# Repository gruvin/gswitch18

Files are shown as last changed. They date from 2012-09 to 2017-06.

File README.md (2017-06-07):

# 18 Switch USB HID class 'Game Controller'

This project implements a USB 'Game Controller' with 18 switch (or button) interface ports, intended 
for use with PC flight simulators, to give additional inputs for external control panels.

No drivers required. 

# About This Project

A friend and I wanted a compact USB game controller interface, to provide at
least 10 switch inputs -- primarily for use with MS Flight Sim X and later, Condor Sailplane simulator.

I had experience with Atmel AVR chips. But I had never worked with USB before. Some Googling quickly 
found Objective Development's [V-USB project](http://www.obdev.at/products/vusb/index.html).

So, I started with a [KiCAD](http://www.kicad-pcb.org) design ...

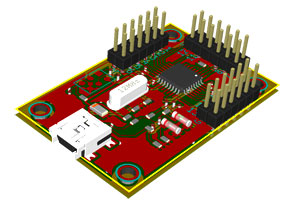
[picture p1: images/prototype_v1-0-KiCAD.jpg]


... and ended up with a working v1.0 prototype ...

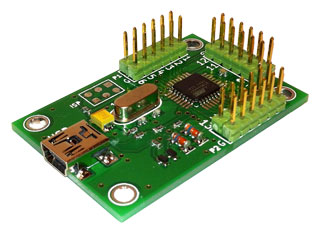
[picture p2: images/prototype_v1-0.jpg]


The image below shows Windows 7 Game Controller Settings / Properties ...

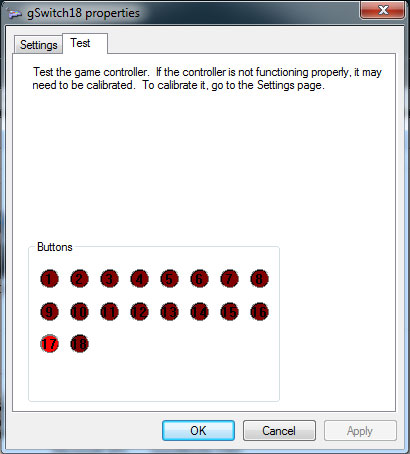
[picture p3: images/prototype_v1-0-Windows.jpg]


Of course, multipleor even all buttons can be used at once.

# Implementation Summary

This board uses an ATmega88p clocked at 12MHz, implementing a V-USB powered
(bit-bang) USB HID compliant game controller interface.

Since this is an HID compliant 'Game Controller' device, no drivers are
required for the host system, which is nice.

I use KiCAD as the PCB design (EDA) suite, only because it is completely free
(as in 'speech' _and_ 'beer') and I have used it very successfully before, for
another, [much larger project](https://github.com/gruvin/gruvin9x).

We get production quality, "prototype" PCB's made in China, using [ITead Studio](http://imall.iteadstudio.com/)'s 
[Open PCB prototyping service](http://imall.iteadstudio.com/open-pcb/pcb-prototyping.html).
These are high quality, fully clear routed, masked and silk-screened, all at a
fraction the price of bare copper, no mask, no silk-screen prototype boards
from, 'the West' and yet also just a fraction the price!

# Make Your Own
All the design files for the PCB (KiCAD) and the Atmel AVR source code is here in this Git repository. Go for it! :-)

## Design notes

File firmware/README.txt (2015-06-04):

This is the source code and hardware design package for the 
gswitch18 USB 18-switch HID 'Game Controller'.

https://github.com/gruvin/gswitch18

The PCB design (in ../hardware/) was created using KiCAD (Windows 7, under VMWare Fusion 5.)

The source code in this folder was developed using GNU avr-gcc, under Apple OS X.

SPECIAL THANKS to Objective Development for their excellent V-USB project 
(http://www.obdev.at/products/vusb/index.html) and to Joonas Pihlajamaa's 
AVR ATtiny USB HID Tutorial, published at his Code and Life blog, 
http://codeandlife.com.

Thanks also to my good friend Shamir, who gave me the idea to do this in 
the first placeand to my beloved wife Berlinda, for putting up with the late 
nights of coding for this and other projects. You're the best!

-- 
Gruvin

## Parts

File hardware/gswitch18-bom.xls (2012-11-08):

nz.element14.com 'next day delivery' cheapest pricing BOM
gswitch18 |  |  |  | as at 2012-11-08
 |  | Farnell UK |  |  |  |  |  |  |  | Per Build | MOQ Qty
Part Ref(s). | Farnell Part No. | Manufacturer | Mfr Part No. | Description | Value | Package | Qty | MOQ | Price Ea. | Amount | Amount
C3, C4 | 721992 (http://nz.element14.com/yageo-phycomp/cc0603jrnpo9bn180/capacitor-0603-18pf-50v/dp/721992) | Yageo | CC0603JRNPO9BN180 | Capacitor (ceramic) | 18p | SM0603 | 2 | 10 | 0.064 | 0.13 | 0.64
C1 | 1362556 (http://nz.element14.com/yageo-phycomp/cc0603krx7r9bb104/capacitor-0603-100nf-50v-x7r/dp/1362556) | Yageo | CC0603KRX7R9BB104 | Capacitor (ceramic) | 0u1 | SM0603 | 2 | 10 | 0.078 | 0.16 | 0.78
C2 | 1862119 (http://nz.element14.com/avx/tajb226k016rnj/capacitor-tant-22uf-16v-2-3ohm/dp/1862119) | AVX | TAJB226K016RNJ | Capacitor (tantalum) | 22u | SM1210 | 1 | 1 | 1.600 | 1.60 | 1.60
R1, R2 | 9330950 (http://nz.element14.com/multicomp/mc-0-063w-0603-1-27r/resistor-0603-27r/dp/9330950) | Multicomp | MC 0.063W 0603 1% 27R | Resistor (thick-film) | 27R | SM0603 | 2 | 50 | 0.010 | 0.02 | 0.50
R5, R6 | 9332138 (http://nz.element14.com/multicomp/mc-0-063w-0603-5-47r/resistor-0603-47r/dp/9332138) | Multicomp | MC 0.063W 0603 5% 47R | Resistor (thick-film) | 47R | SM0603 | 2 | 50 | 0.010 | 0.02 | 0.50
R3 | 9331140 (http://nz.element14.com/multicomp/mc-0-063w-0603-1-3k9/resistor-0603-3k9/dp/9331140) | Multicomp | MC 0.063W 0603 1% 3K9 | Resistor (thick-film) | 3K9 | SM0603 | 1 | 50 | 0.010 | 0.01 | 0.50
R7 | 9331352 (http://nz.element14.com/multicomp/mc-0-063w-0603-1-5k6/resistor-0603-5k6-1-0-063w/dp/9331352) | Multicomp | MC 0.063W 0603 1% 5K6 | Resistor (thick-film) | 5K6 | SM0603 | 1 | 50 | 0.010 | 0.01 | 0.50
D1, D2 | 1456534 (http://nz.element14.com/jsp/search/productdetail.jsp?sku=1456534) | Bourns | CD0603-B00340 | Schottky Diode (fast recovery) | Sctky 30mA | SM0603 | 2 | 1 | 0.513 | 1.03 | 1.03
D2, D3 | 8735450 (http://nz.element14.com/nxp/bzv55-c3v6/diode-zener-3-6v-5-sod-80/dp/8735450) | NXP | BZV55-C3V6 | Zenor Didoe 3.6V | DO-213AC (Glass) | SM1206 | 2 | 5 | 0.163 | 0.33 | 0.82
P1, P2, P3 | 1248136 (http://nz.element14.com/te-connectivity-amp/826925-6/header-straight-2x6way/dp/1248136) | TE Connectivity | 826925-6 | Pin Header | 2x6 | through-hole 2.54mm | 3 | 10 | 1.360 | 4.08 | 13.60
IC1 | 1636946 (http://nz.element14.com/atmel/atmega88p-20au/8-bit-mcu-8k-fla-2-7-5-5v-tqfp32/dp/1636946) | Atmel | ATmega88P | MCU | 20MHz | TQFP | 1 | 1 | 7.980 | 7.98 | 7.98
P4 | 1125348 (http://nz.element14.com/molex/675031020/socket-usb-mini-b-smt-w-pegs/dp/1125348) | Molex | 675031020 | USB-B mini socket | USB-B mini | SMD | 1 | 1 | 3.46 | 3.46 | 3.46
 |  |  |  |  |  |  |  |  |  | 18.82 | 31.90
Prices are NZD currency and most lkely out of date.

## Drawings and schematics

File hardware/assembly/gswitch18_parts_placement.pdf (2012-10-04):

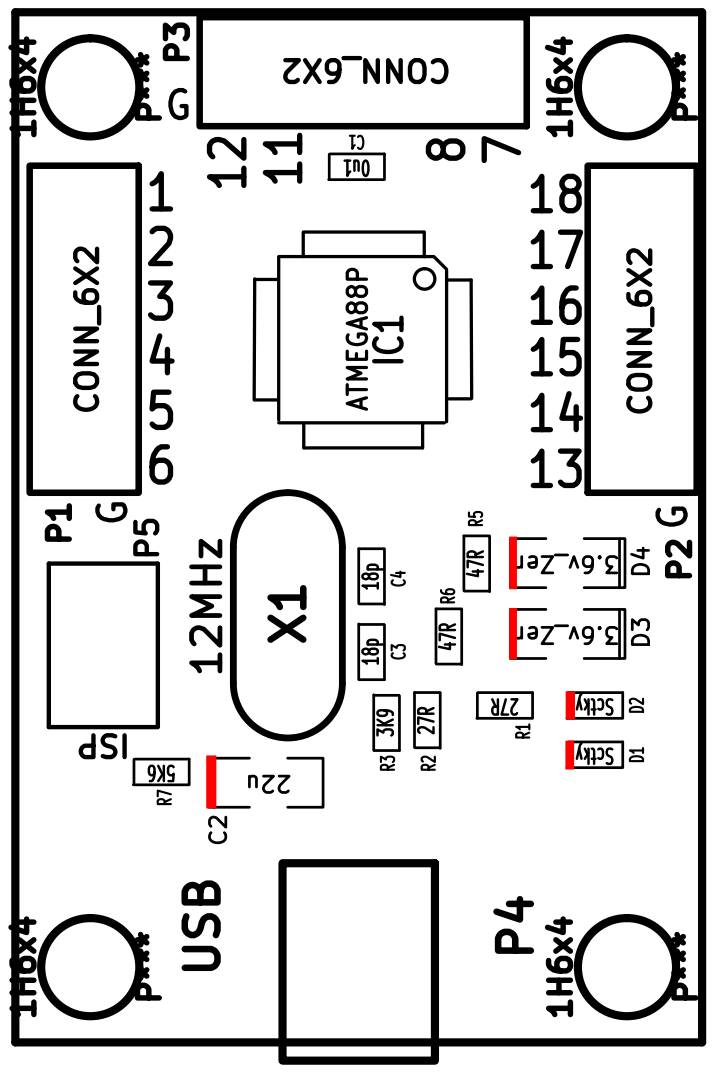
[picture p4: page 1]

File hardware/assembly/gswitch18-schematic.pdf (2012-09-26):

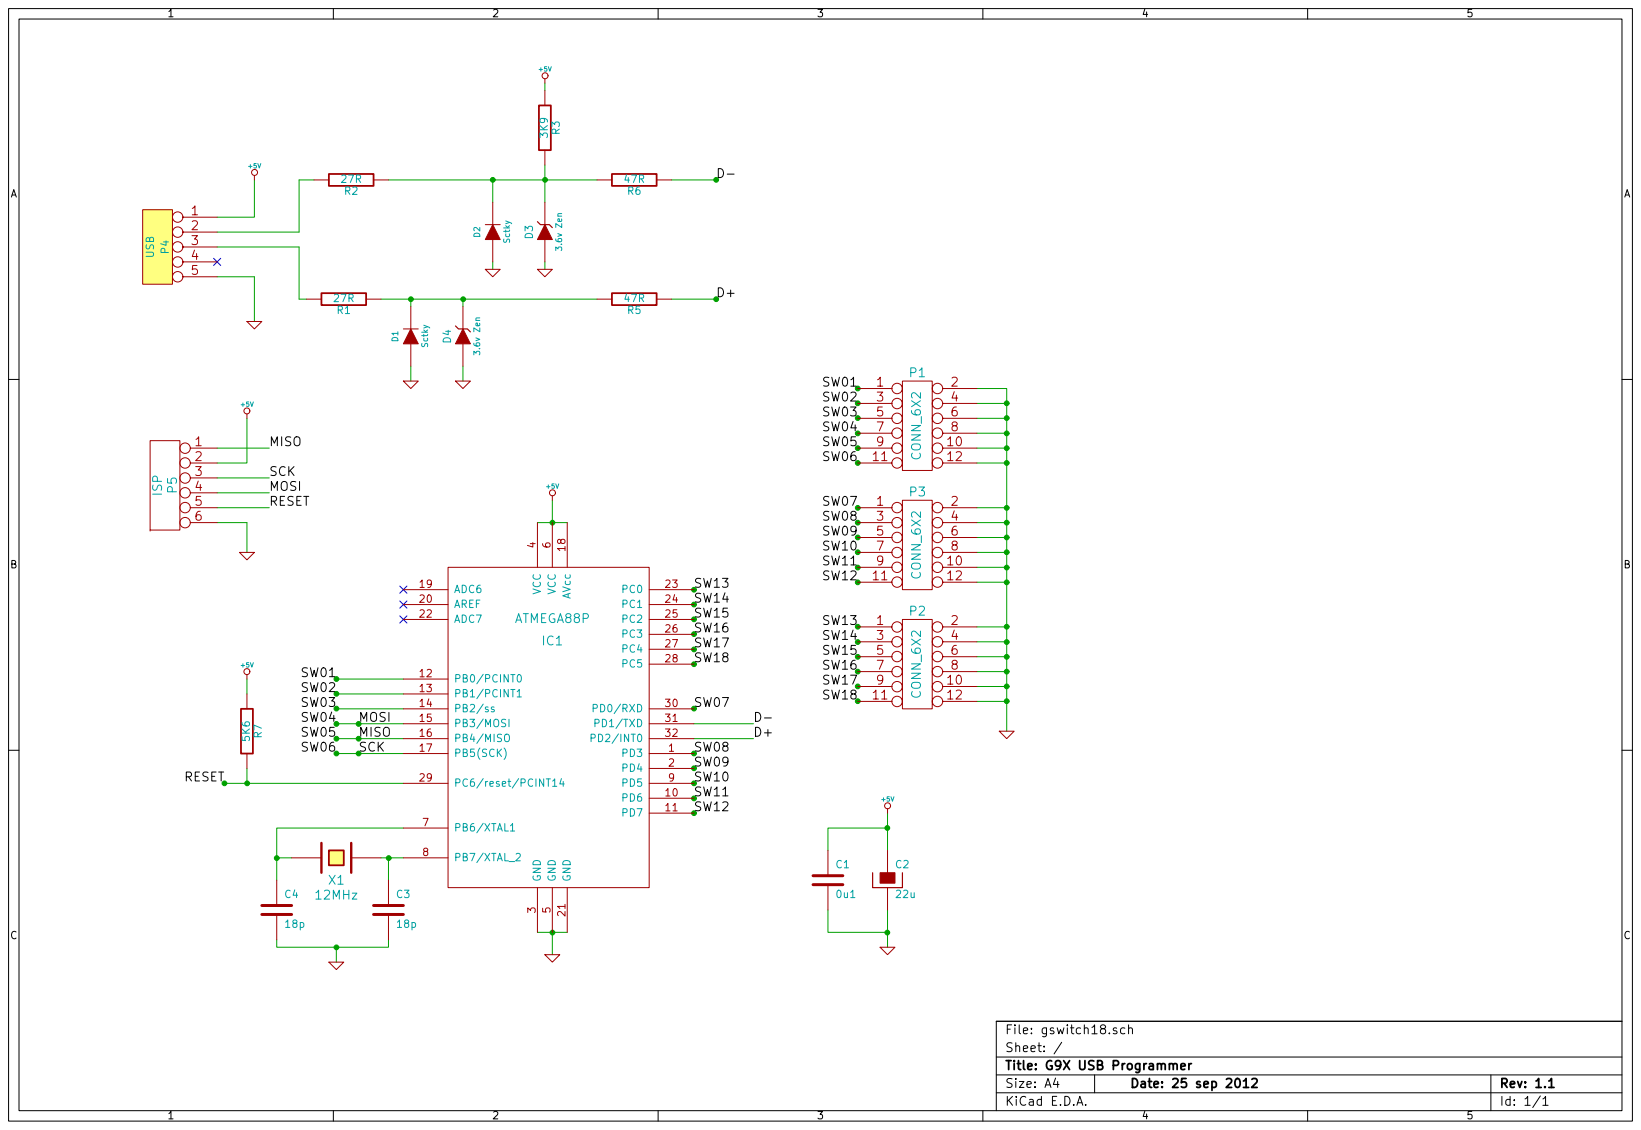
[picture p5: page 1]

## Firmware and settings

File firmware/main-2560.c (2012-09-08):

/**
 * Project: gswitch18 USB HID Game Controller
 * Author: Gruvin <gruvin@gmail.com>
 * Based on Joonas Pihlajamaa's AVR ATtiny USB HID Tutorial, published at his 
 * Code and Life blog, http://codeandlife.com.
 * Copyright: (c) 2012 by Bryan J. Rentoul (gruvin)
 * Copyright: (c) 2008 by OBJECTIVE DEVELOPMENT Software GmbH
 * License: GNU GPL v3 (see License.txt)
 */
#include <avr/io.h>
#include <avr/interrupt.h>
#include <avr/wdt.h>

#include "usbdrv.h"

#include <util/delay.h>

/*
PROGMEM const char usbHidReportDescriptor[52] = { // USB report descriptor, size must match usbconfig.h
    0x05, 0x01,                    // USAGE_PAGE (Generic Desktop)
    0x09, 0x05,                    // USAGE (Mouse=0x02, GamePad=0x05)
    0xa1, 0x01,                    // COLLECTION (Application)
    0x09, 0x01,                    //   USAGE (Pointer)
    0xA1, 0x00,                    //   COLLECTION (Physical)
    0x05, 0x09,                    //     USAGE_PAGE (Button)
    0x19, 0x01,                    //     USAGE_MINIMUM
    0x29, 0x03,                    //     USAGE_MAXIMUM
    0x15, 0x00,                    //     LOGICAL_MINIMUM (0)
    0x25, 0x01,                    //     LOGICAL_MAXIMUM (1)
    0x95, 0x03,                    //     REPORT_COUNT (3)
    0x75, 0x01,                    //     REPORT_SIZE (1)
    0x81, 0x02,                    //     INPUT (Data,Var,Abs)

    // pad out the 5 remaining bits of unused buttons (constants)
    0x95, 0x01,                    //     REPORT_COUNT (1)
    0x75, 0x05,                    //     REPORT_SIZE (5)
    0x81, 0x03,                    //     INPUT (Const,Var,Abs)

    0x05, 0x01,                    //     USAGE_PAGE (Generic Desktop)
    0x09, 0x30,                    //     USAGE (X)
    0x09, 0x31,                    //     USAGE (Y)
    0x09, 0x38,                    //     USAGE (Wheel)
    0x15, 0x81,                    //     LOGICAL_MINIMUM (-127)
    0x25, 0x7F,                    //     LOGICAL_MAXIMUM (127)
    0x75, 0x08,                    //     REPORT_SIZE (8)
    0x95, 0x03,                    //     REPORT_COUNT (3)
    0x81, 0x06,                    //     INPUT (Data,Var,Rel)
    0xC0,                          //   END_COLLECTION
    0xC0,                          // END COLLECTION
};
*/

// USB report descriptor, size must match USB_CFG_HID_REPORT_DESCRIPTOR_LENGTH in usbconfig.h
PROGMEM const char usbHidReportDescriptor[] = {
    0x05, 0x01,                    // USAGE_PAGE (Generic Desktop)
    0x09, 0x05,                    // USAGE_ID (GamePad=0x05)
    0xA1, 0x00,                    // COLLECTION (Physical)
    0x05, 0x09,                    //   USAGE_PAGE (Button)
    0x19, 0x01,                    //   USAGE_MINIMUM (button 1)
    0x29, 0x14,                    //   USAGE_MAXIMUM (button 20)
    0x15, 0x00,                    //   LOGICAL_MINIMUM (0)
    0x25, 0x01,                    //   LOGICAL_MAXIMUM (1)
    0x95, 0x14,                    //   REPORT_COUNT (20)
    0x75, 0x01,                    //   REPORT_SIZE (1)
    0x81, 0x02,                    //   INPUT (Data,Var,Abs)

    // pad out remaining 4 bits for missing buttons 21 to 24
    0x95, 0x01,                    //   REPORT_COUNT (1)
    0x75, 0x04,                    //   REPORT_SIZE (4)
    0x81, 0x03,                    //   INPUT (Const,Var,Abs)

    0xC0                           // END COLLECTION
};

typedef struct{ // USB 1.1 low speed devices limited to max 8 bytes
    uchar   buttonMask0; // buttons 0 - 7
    uchar   buttonMask1; // buttons 8 - 15
    uchar   buttonMask2; // buttons 16 - 19 (plus 4 unused)
} report_t;

static report_t reportBuffer;
static uchar    idleRate;   /* repeat rate for keyboards, never used for mice */

usbMsgLen_t usbFunctionSetup(uchar data[8]) {
    usbRequest_t *rq = (void *)data;

    // The following requests are never used. But since they are required by
    // the specification, we implement them in this example.
    if((rq->bmRequestType & USBRQ_TYPE_MASK) == USBRQ_TYPE_CLASS) {
        if(rq->bRequest == USBRQ_HID_GET_REPORT) {  
            // wValue: ReportType (highbyte), ReportID (lowbyte)
            usbMsgPtr = (void *)&reportBuffer; // we only have this one
            return sizeof(reportBuffer);
        } else if(rq->bRequest == USBRQ_HID_GET_IDLE) {
            usbMsgPtr = &idleRate;
            return 1;
        } else if(rq->bRequest == USBRQ_HID_SET_IDLE) {
            idleRate = rq->wValue.bytes[1];
        }
    }
    
    return 0; // by default don't return any data
}

int main() {
  uchar i, tg, tc, tb;

  // Set up I/O port data directions and initial states
  // G9X v4.x PCB being used as devlopment platform for now
  DDRA = 0xff;  PORTA = 0x00; // LCD data
  DDRB = 0;     PORTB = 0x30; // pull-ups for Train_Sw and IDL2
  DDRC = 0x3f;  PORTC = 0xc0; // 7:AilDR_Sw, 6:EleDr_Sw, LCD[5,4,3,2,1], 0:LED_back-light
  DDRL = 0x80;  PORTL = 0x7f; // 7: Hold_PWR_On (1=On, default Off), 6:Jack_Presence_TTL, 5-0: User Button inputs
  DDRE = 0x04;  PORTE = 0x04; // Bit 3=BUZZER
  DDRG = 0;     PORTG = 0x2d; // Pull-ups for RudDr_Sw, TCut_Sw, IDL1_Sw, Gear_Sw
  DDRJ = 0;     PORTJ = 0xff; // Pull-ups for all trim switches

  _delay_us(10000); // let the I/O ports settle

  wdt_enable(WDTO_1S); // enable 1s watchdog timer

  usbInit();

  usbDeviceDisconnect(); // enforce re-enumeration
  for(i = 0; i<250; i++) { // wait 500 ms
    wdt_reset(); // keep the watchdog happy
    _delay_ms(2);
  }
  usbDeviceConnect();

  sei(); // Enable interrupts after re-enumeration

  while(1) {
    wdt_reset(); // keep the watchdog happy
    usbPoll();

    if(usbInterruptIsReady()) { // if the interrupt is ready, feed data

      tg = ~PING & 0x2d;
      tc = ~PINC & 0xc0;
      tb = ~PINB & 0x30;

      reportBuffer.buttonMask0 = 
          ((~tg & 0x04)<<5)    // bit  7 Thr_Cut
        | ((~tg & 0x01)<<6)    // bit  6 Rud_Sw
        | ((~tc & 0x40)>>1)    // bit  5 Ele_DR
        | ((tg & 0x08)<<1)     // bit  4 IDL1
        | ((tb & 0x10)>>1)     // bit  3 IDL2
        | ((~tc & 0x80)>>5)    // bit  2 Ail_DR
        | ((~tg & 0x20)>>4)    // bit  1 Gear_Sw
        | ((~tb & 0x20)>>5);   // bit  0 Trainer_Sw

      reportBuffer.buttonMask1 = ~PINJ; // front panel trim switches
      reportBuffer.buttonMask2 = (~PINL & 0x3f); // front panel key-pad buttons (G9X)

      usbSetInterrupt((void *)&reportBuffer, sizeof(reportBuffer));
    }
  }

  return 0;
}

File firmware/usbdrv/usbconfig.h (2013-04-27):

/* Name: usbconfig.h
 * Project: V-USB, virtual USB port for Atmel's(r) AVR(r) microcontrollers
 * Author: Christian Starkjohann
 * Creation Date: 2005-04-01
 * Tabsize: 4
 * Copyright: (c) 2005 by OBJECTIVE DEVELOPMENT Software GmbH
 * License: GNU GPL v2 (see License.txt), GNU GPL v3 or proprietary (CommercialLicense.txt)
 * This Revision: $Id$
 */

#ifndef __usbconfig_h_included__
#define __usbconfig_h_included__

/*
General Description:
This file is an example configuration (with inline documentation) for the USB
driver. It configures V-USB for USB D+ connected to Port D bit 2 (which is
also hardware interrupt 0 on many devices) and USB D- to Port D bit 4. You may
wire the lines to any other port, as long as D+ is also wired to INT0 (or any
other hardware interrupt, as long as it is the highest level interrupt, see
section at the end of this file).
*/

/* ---------------------------- Hardware Config ---------------------------- */

#define USB_CFG_IOPORTNAME      D
/* This is the port where the USB bus is connected. When you configure it to
 * "B", the registers PORTB, PINB and DDRB will be used.
 */
#define USB_CFG_DMINUS_BIT      1
/* This is the bit number in USB_CFG_IOPORT where the USB D- line is connected.
 * This may be any bit in the port.
 */
#define USB_CFG_DPLUS_BIT       2
/* This is the bit number in USB_CFG_IOPORT where the USB D+ line is connected.
 * This may be any bit in the port. Please note that D+ must also be connected
 * to interrupt pin INT0! [You can also use other interrupts, see section
 * "Optional MCU Description" below, or you can connect D- to the interrupt, as
 * it is required if you use the USB_COUNT_SOF feature. If you use D- for the
 * interrupt, the USB interrupt will also be triggered at Start-Of-Frame
 * markers every millisecond.]
 */
#define USB_CFG_CLOCK_KHZ       (F_CPU/1000)
/* Clock rate of the AVR in kHz. Legal values are 12000, 12800, 15000, 16000,
 * 16500, 18000 and 20000. The 12.8 MHz and 16.5 MHz versions of the code
 * require no crystal, they tolerate +/- 1% deviation from the nominal
 * frequency. All other rates require a precision of 2000 ppm and thus a
 * crystal!
 * Since F_CPU should be defined to your actual clock rate anyway, you should
 * not need to modify this setting.
 */
#define USB_CFG_CHECK_CRC       0
/* Define this to 1 if you want that the driver checks integrity of incoming
 * data packets (CRC checks). CRC checks cost quite a bit of code size and are
 * currently only available for 18 MHz crystal clock. You must choose
 * USB_CFG_CLOCK_KHZ = 18000 if you enable this option.
 */

/* ----------------------- Optional Hardware Config ------------------------ */

/* #define USB_CFG_PULLUP_IOPORTNAME   D */
/* If you connect the 1.5k pullup resistor from D- to a port pin instead of
 * V+, you can connect and disconnect the device from firmware by calling
 * the macros usbDeviceConnect() and usbDeviceDisconnect() (see usbdrv.h).
 * This constant defines the port on which the pullup resistor is connected.
 */
/* #define USB_CFG_PULLUP_BIT          4 */
/* This constant defines the bit number in USB_CFG_PULLUP_IOPORT (defined
 * above) where the 1.5k pullup resistor is connected. See description
 * above for details.
 */

/* --------------------------- Functional Range ---------------------------- */
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

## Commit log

2012-09-08 Version 1.0 pre-production prototype.
    NOTE: Firmware is currently for ATmega2560 based G9X v4.2 RC controller board.
    (See gruvin9x.googlecode.com.) This was used for testing code function.
    I Will convert to the ATmega88P in due course -- probably about the
    time I receive the first prototype PCBs.
    SPECIAL THANKS to Objective Development for their excellent V-USB project
    (http://www.obdev.at/products/vusb/index.html) and to Joonas Pihlajamaa's
    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
    [gswitch18-Back.gbl, gswitch18-Front.gtl, gswitch18-Mask_Back.gbs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]
2012-09-24 Some Wings 3D work. Man that program is hard to use!
    [gswitch18-Back.gbl, gswitch18-Front.gtl, gswitch18-Mask_Back.gbs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]
2012-09-25 Version 1.0 prototype tested working. [MILESTONE]
    Firmware modified for ATmega88p. Debugged and tested OK.
    (Old [main].c etc backed up to [etc]-2560.*)
    There were some errors with the PCB design around the
    USB socket ground pin and the front silk-screen switch
    number labels.
    [gswitch18.brd, gswitch18.sch]
2012-09-25 Decided to match PCB design and code to prototype PCB silk screen, so as not to waste several boards.
    This should be the final v1.0 version now, since everything
    appears to be working and labelled correctly on the board.
    Yay \o/
    (Also added some wiki images with this commit.)
    [gswitch18.brd, gswitch18.sch]
2012-09-26 Version bumped to v1.1.
    Improved component placement PDF (and made the file in assembly/ that,
    instead of an old schematic as before, in error. -/)
    Added PDF schematic in assembly/
    [gswitch18.brd, gswitch18.sch]
2012-09-26 Made all ISP pads top-side only, so I dont have to fill them with solder each time it comes to loading firmware. ;-)
    [gswitch18-Back.gbl, gswitch18-Front.gtl, gswitch18-Mask_Back.gbs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]
2012-09-26 Fixed fuse writing script so it actually works. Yay \o/
2012-09-26 Wings 6x2 pin arrays now replace KiCAD default versions.
    [gswitch18.brd]
2012-09-27 Corrected P2's 'G' label position.
    [gswitch18.brd]
2012-09-27 3D parts updated.
    [gswitch18-Comments.gbr, gswitch18-Drawings.gbr]
2012-09-27 Crazy-as 3D part upgrade! :-P
    [gswitch18.brd]
2012-10-01 Oops! It's a good idea to set all the switch inputs to INPUT instead of output. Otherwise, strangely enough, the poor little ATmega get REALLY hot when you turn on several switches at once! Doh.
    Lysdexia strikes again.
2012-10-04 Manually added polarity markers to diodes and cap in the parts placement PDF.
    Need to look into why the KiCAD modules are not correct for the zenors.
    Probably using a 1206POL instead of the actual diode footprint, if it even
    exists.
2012-10-04 PCB vias changed to 0.65mm with 0.4mm holes. This makes for better looking boards, especially when vias are tented, which is my preference for non-green mask boards.
    [gswitch18.brd]
2012-10-05 Production version 1.1 frozen in new archive folder.
    DigiKey BOM added.
    [gswitch18-Back.gbl, gswitch18-Comments.gbr, gswitch18-Drawings.gbr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]
2012-11-08 no comment
    [gswitch18-bom.xls, gswitch18_v1.1_bom.xls]
2012-11-08 BOM, finally completed. (NZ.element14.com only, at this stage.)
    [gswitch18-bom.xls]
2013-04-27 A review of the shared PID usage file (USB-IDs-for-free.txt) revelaed that we were using the wrong VID/PID pair for a USB Joystock class HID device. Changed to 0x16c0/0x27dc, accordingly.
    [usbconfig.h]
2013-04-27 Decided it best to move defines for VID/PID to main.c, so it's clearly visible in the main firmware code file.
2015-06-04 Added archive folder, missed by Google Code export
    [gswitch18-Back.gbl, gswitch18-Comments.gbr, gswitch18-Drawings.gbr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]
2015-07-27 PCB updates. Wider tracks for CNC routing the board. (I used this board as my first test, to get things set up and working well.)
    [gswitch18.brd]
2016-11-25 Updated production files
    [gswitch18-B_Mask.gbs, gswitch18-B_Paste.gbp, gswitch18-B_SilkS.gbo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]
